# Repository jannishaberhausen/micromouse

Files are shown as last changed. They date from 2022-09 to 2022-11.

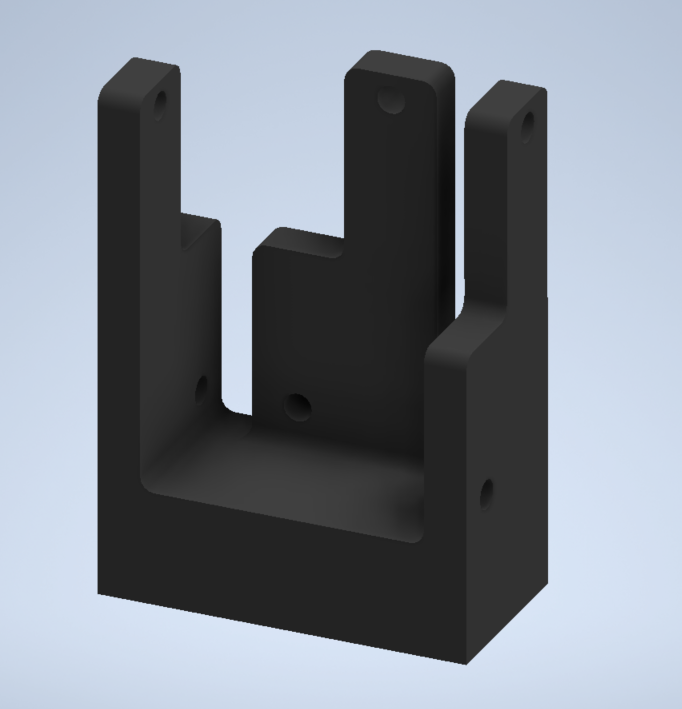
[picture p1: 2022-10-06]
CAD/3d_print/png/sg_sensor_mount.PNG

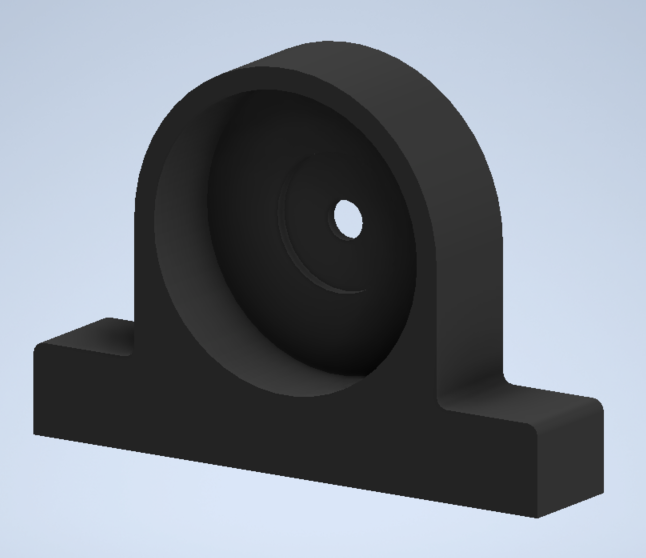
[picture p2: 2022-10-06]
CAD/3d_print/png/sg_motor_mount.PNG

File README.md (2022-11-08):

# SPEEDY GONZALES - A MICROMOUSE PROJECT
## Don't Call It Micromouse - Call It Megamouse
### Ever wondered what Speedy Gonzales does nowadys?

---

**From Wikipedia:**
Micromouse is an event where small robot mice solve a 16×16 maze. It began in the late 1970s. Events are held worldwide, and are most popular in the UK, U.S., Japan, Singapore, India, South Korea and becoming popular in subcontinent countries such as Sri Lanka.

The maze is made up of a 16×16 grid of cells, each 180 mm square with walls 50 mm high. The mice are completely autonomous robots that must find their way from a predetermined starting position to the central area of the maze unaided. The mouse needs to keep track of where it is, discover walls as it explores, map out the maze and detect when it has reached the goal. Having reached the goal, the mouse will typically perform additional searches of the maze until it has found an optimal route from the start to the finish. Once the optimal route has been found, the mouse will run that route in the shortest possible time.

Competitions and conferences are still run regularly.

----

Watch a video of Speedy Gonzales in action [here](https://youtu.be/TwjPslRqBsg).

### Getting Started

Notice `main.c` starts the T1 timer `startTimer()` and the finite state machine (FSM) `plannerFSM()` which realizes the planning of mouse motions before running in an infinite loop in which the behaviour is controlled by the planning FSM and the motion FSM which in turn is called every 50 ms by a timer interupt in T1 (see `timer.c`).
    
The most important motions (and their respective controllers) are defined in `mouse_motion.c` and the business logic for the path planning is implemented in `pathfinder.c`.

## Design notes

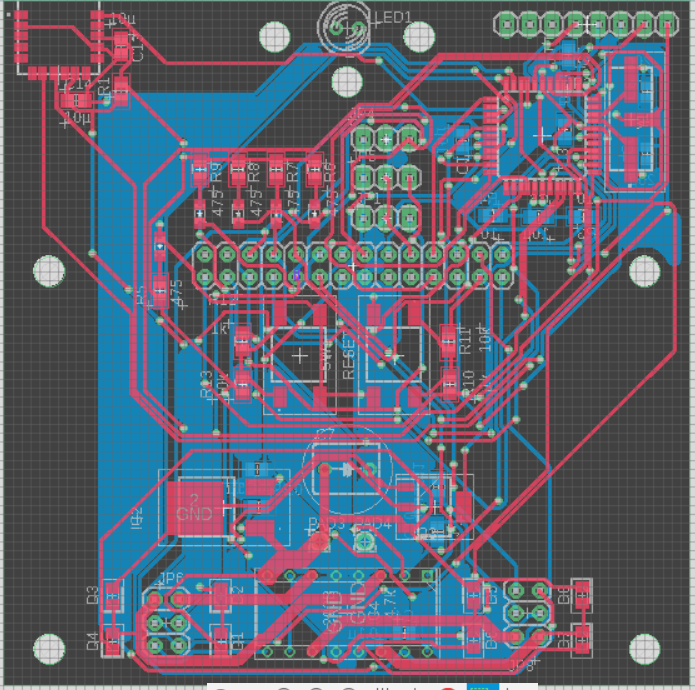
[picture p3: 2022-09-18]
CAD/PCB/speedy_gonzales_board.PNG

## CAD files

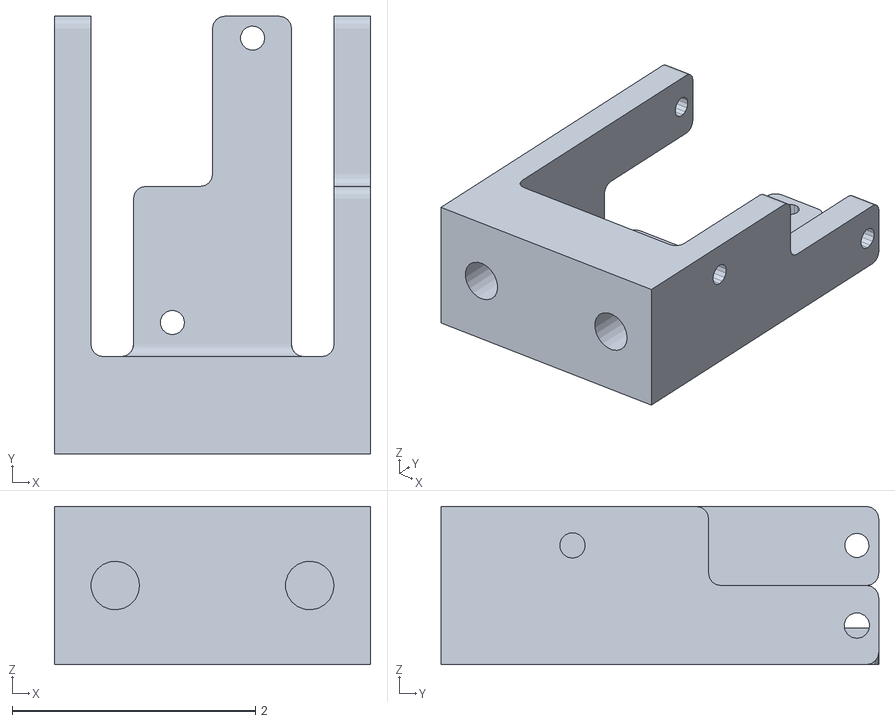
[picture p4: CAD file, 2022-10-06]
CAD/3d_print/stl/sg_sensor_mount.stl
2.60 x 3.60 x 1.30

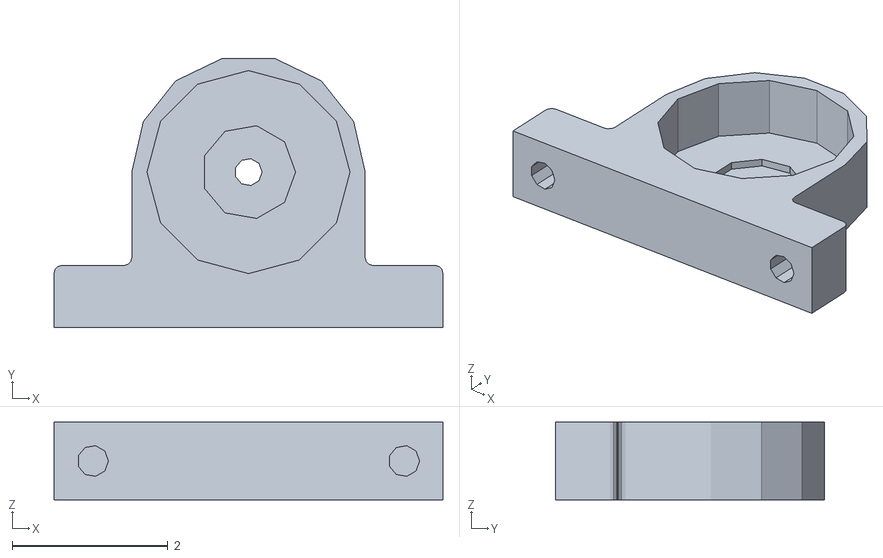
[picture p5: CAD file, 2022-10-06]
CAD/3d_print/stl/sg_motor_mount.stl
5.00 x 3.46 x 1.00

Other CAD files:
CAD/3d_print/dwg/sg_motor_mount.dwg
CAD/3d_print/dwg/sg_sensor_mount.dwg
CAD/3d_print/parts/sg_motor_mount.ipt
CAD/3d_print/parts/sg_sensor_mount.ipt

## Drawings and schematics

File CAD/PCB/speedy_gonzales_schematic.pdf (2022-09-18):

# AN5 AN⁵

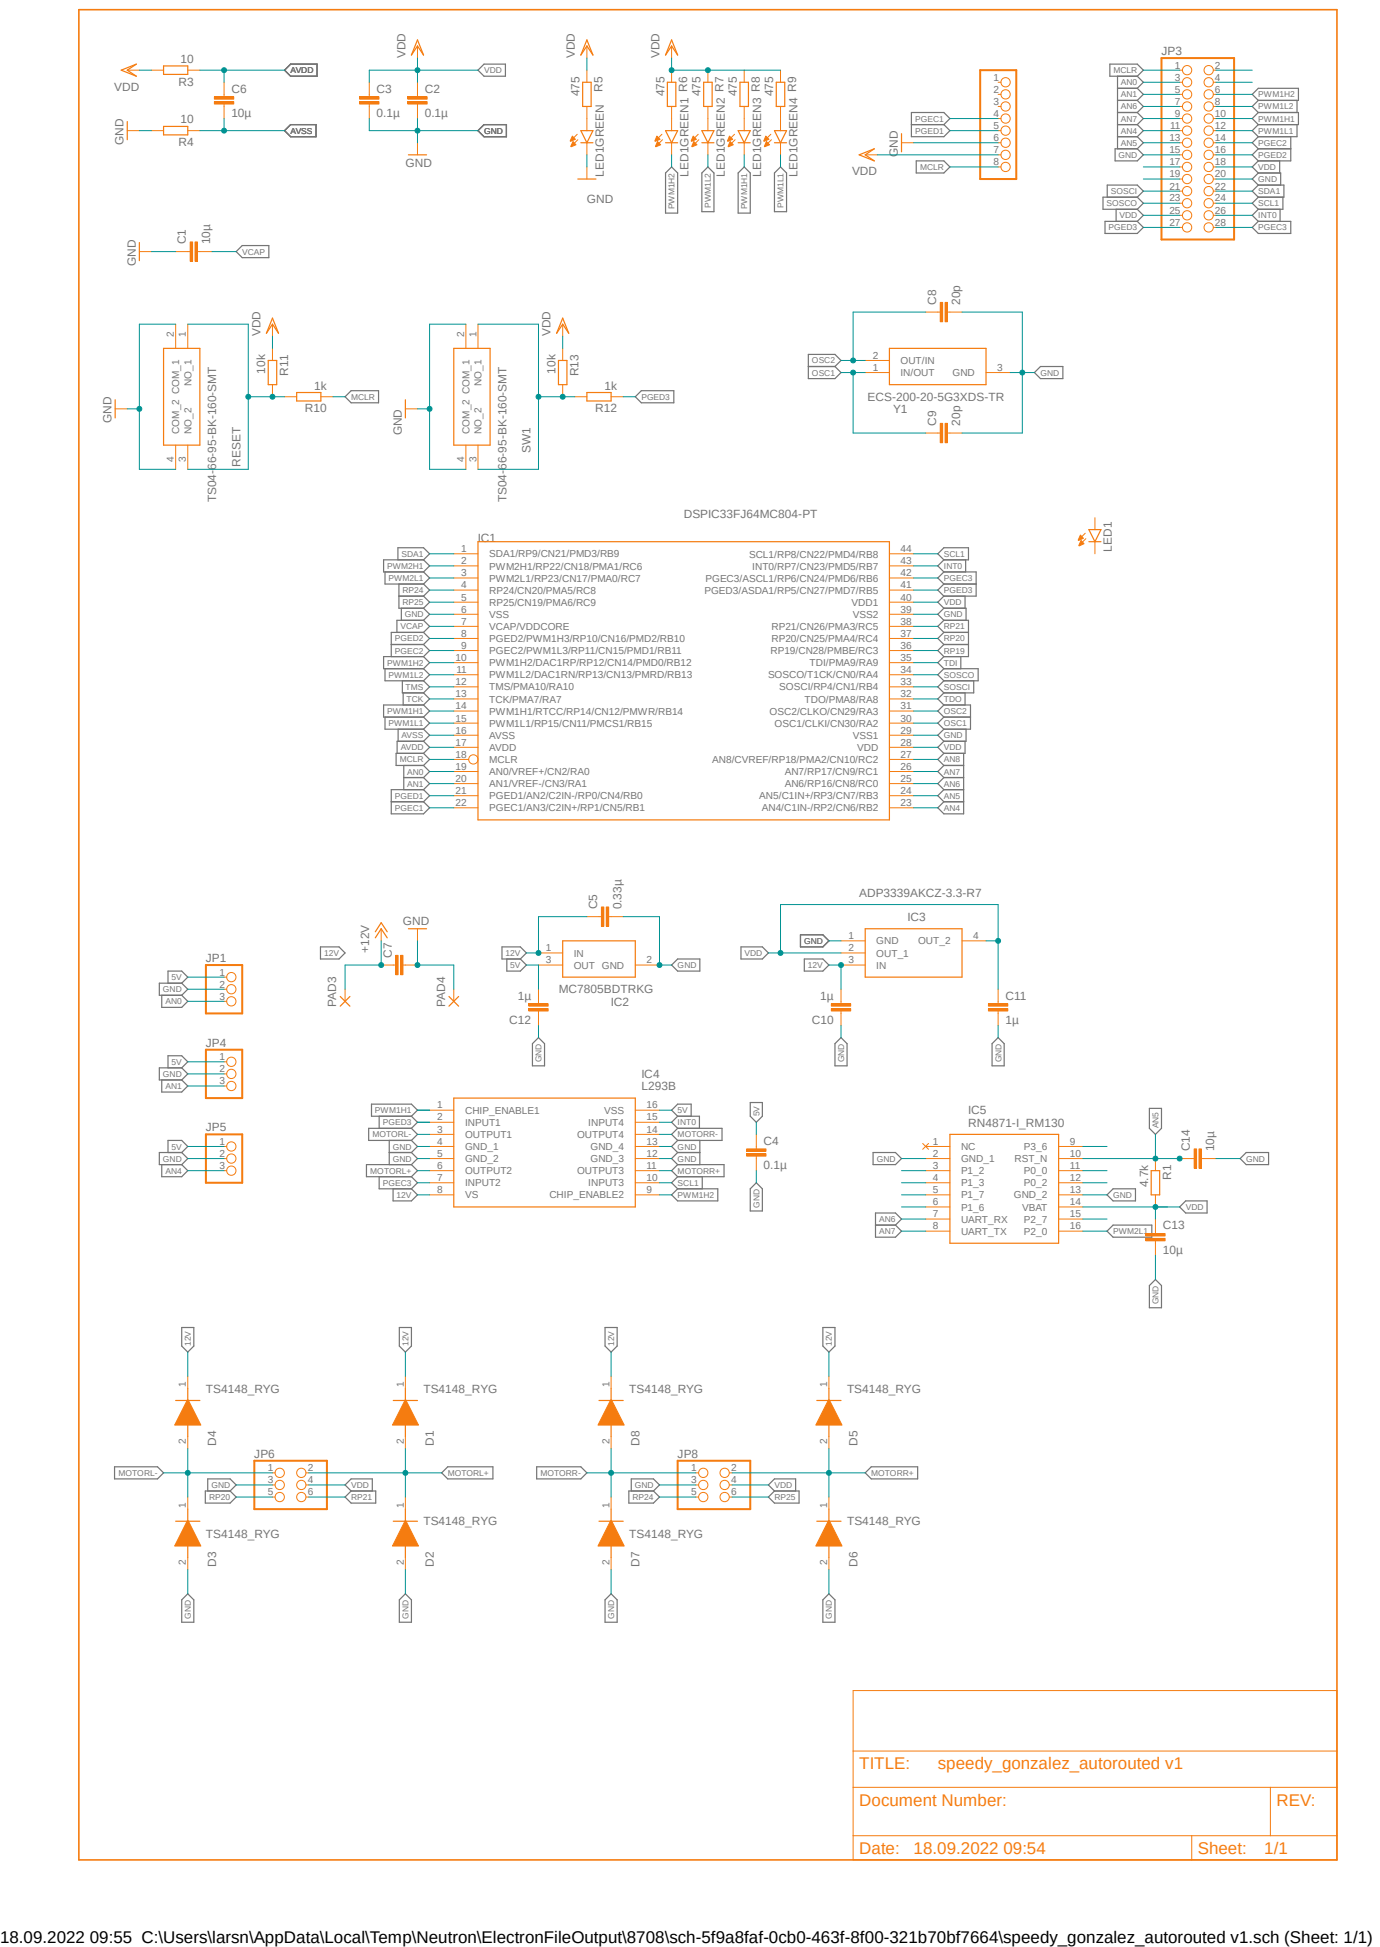
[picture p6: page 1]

GND GND

Document Number: | REV:

Date: 18.09.2022 09:54 | Sheet: 1/1

18.09.2022 09:55 C:\Users\larsn\AppData\Local\Temp\Neutron\ElectronFileOutput\8708\sch-5f9a8faf-0cb0-463f-8f00-321b70bf7664\speedy_gonzalez_autorouted v1.sch (Sheet: 1/1)

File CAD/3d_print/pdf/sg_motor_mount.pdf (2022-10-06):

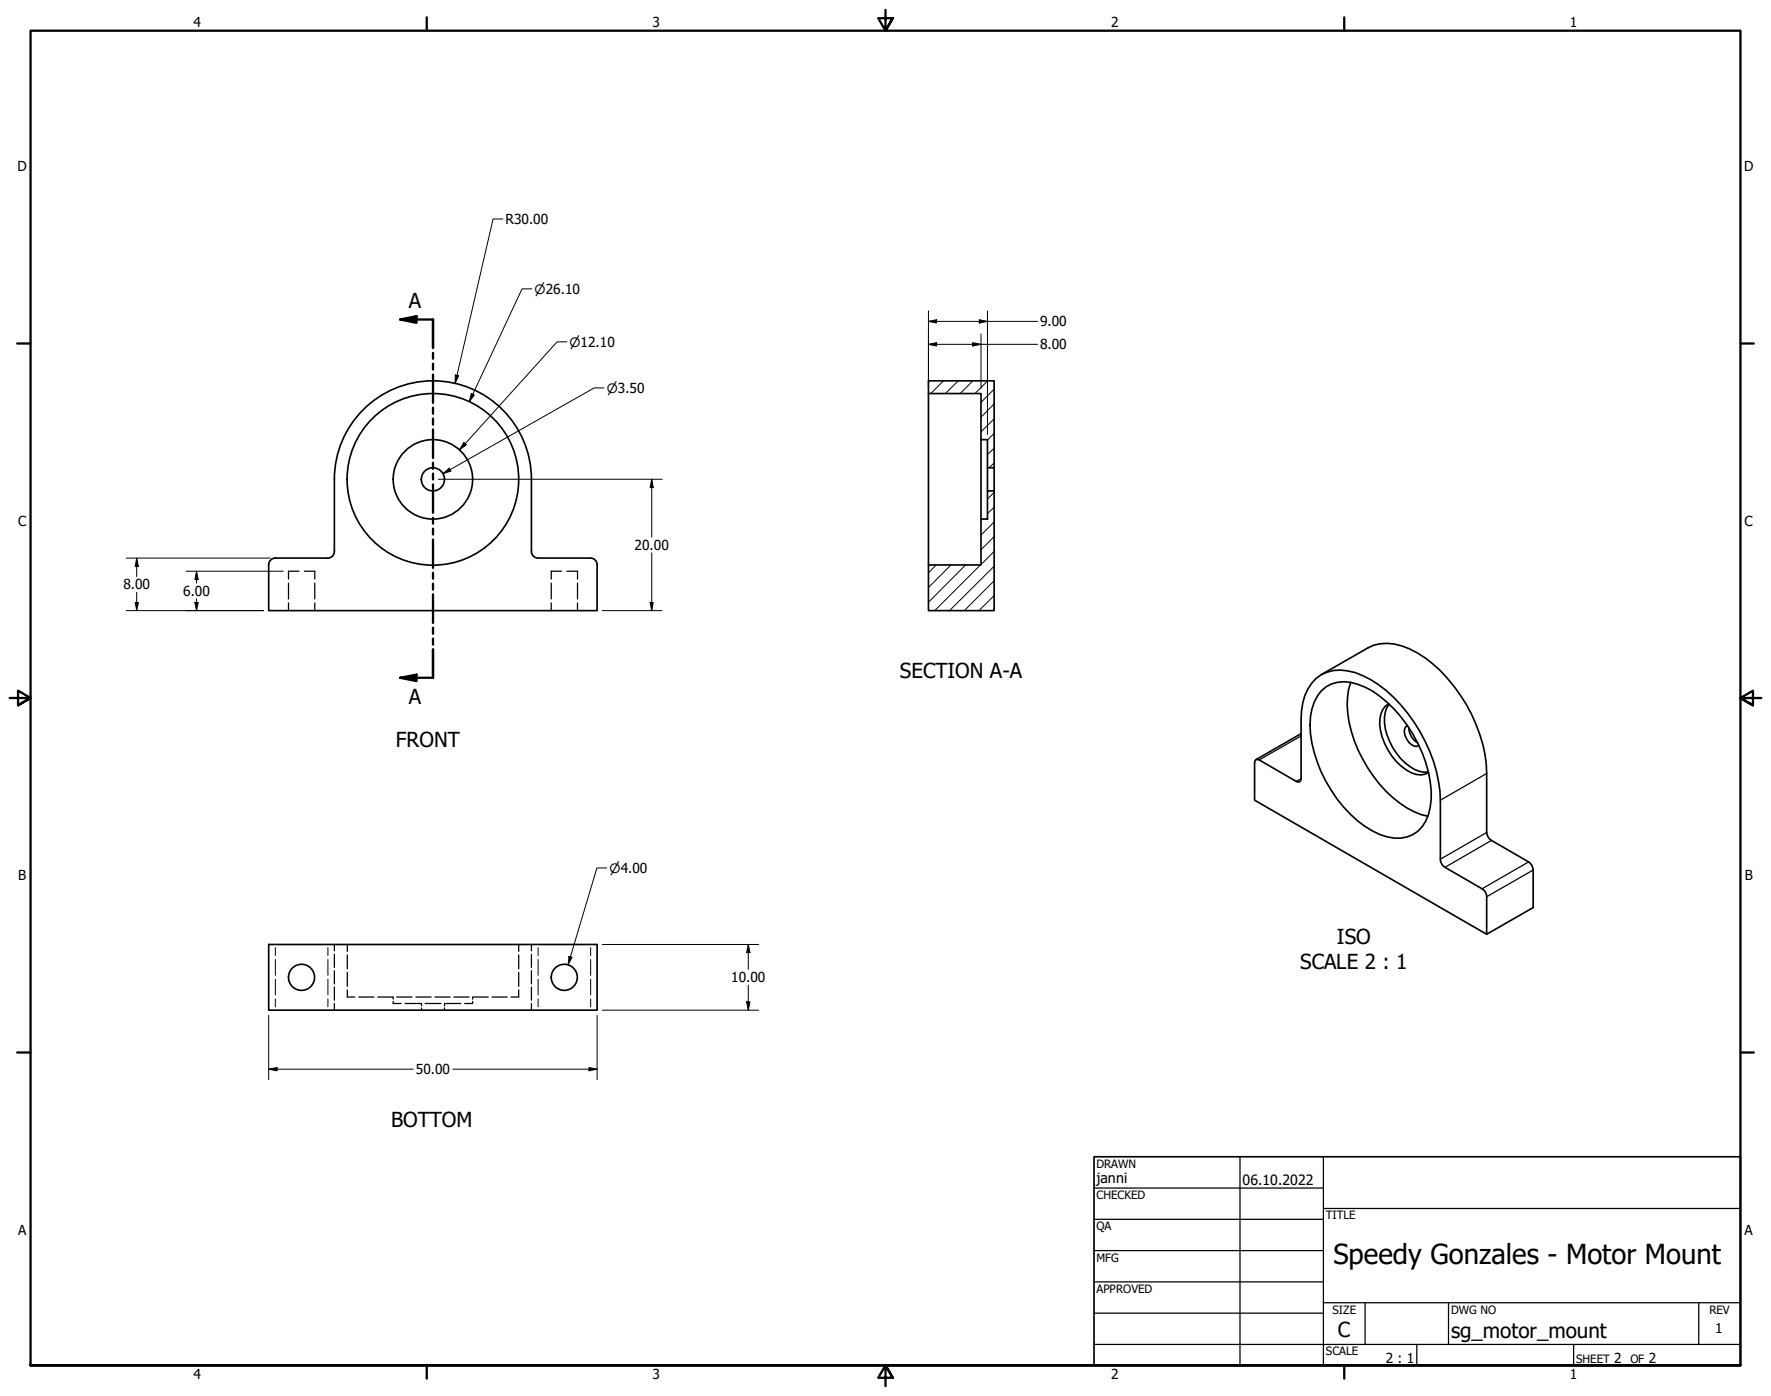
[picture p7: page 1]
SCALE 2 : 1; SECTION A-A

DRAWN janni | 06.10.2022

CHECKED

TITLE
Speedy Gonzales - Motor Mount

MFG

APPROVED

SIZE C | DWG NO sg_motor_mount | REV 1

SCALE 2 : 1 | | SHEET 2 OF 2

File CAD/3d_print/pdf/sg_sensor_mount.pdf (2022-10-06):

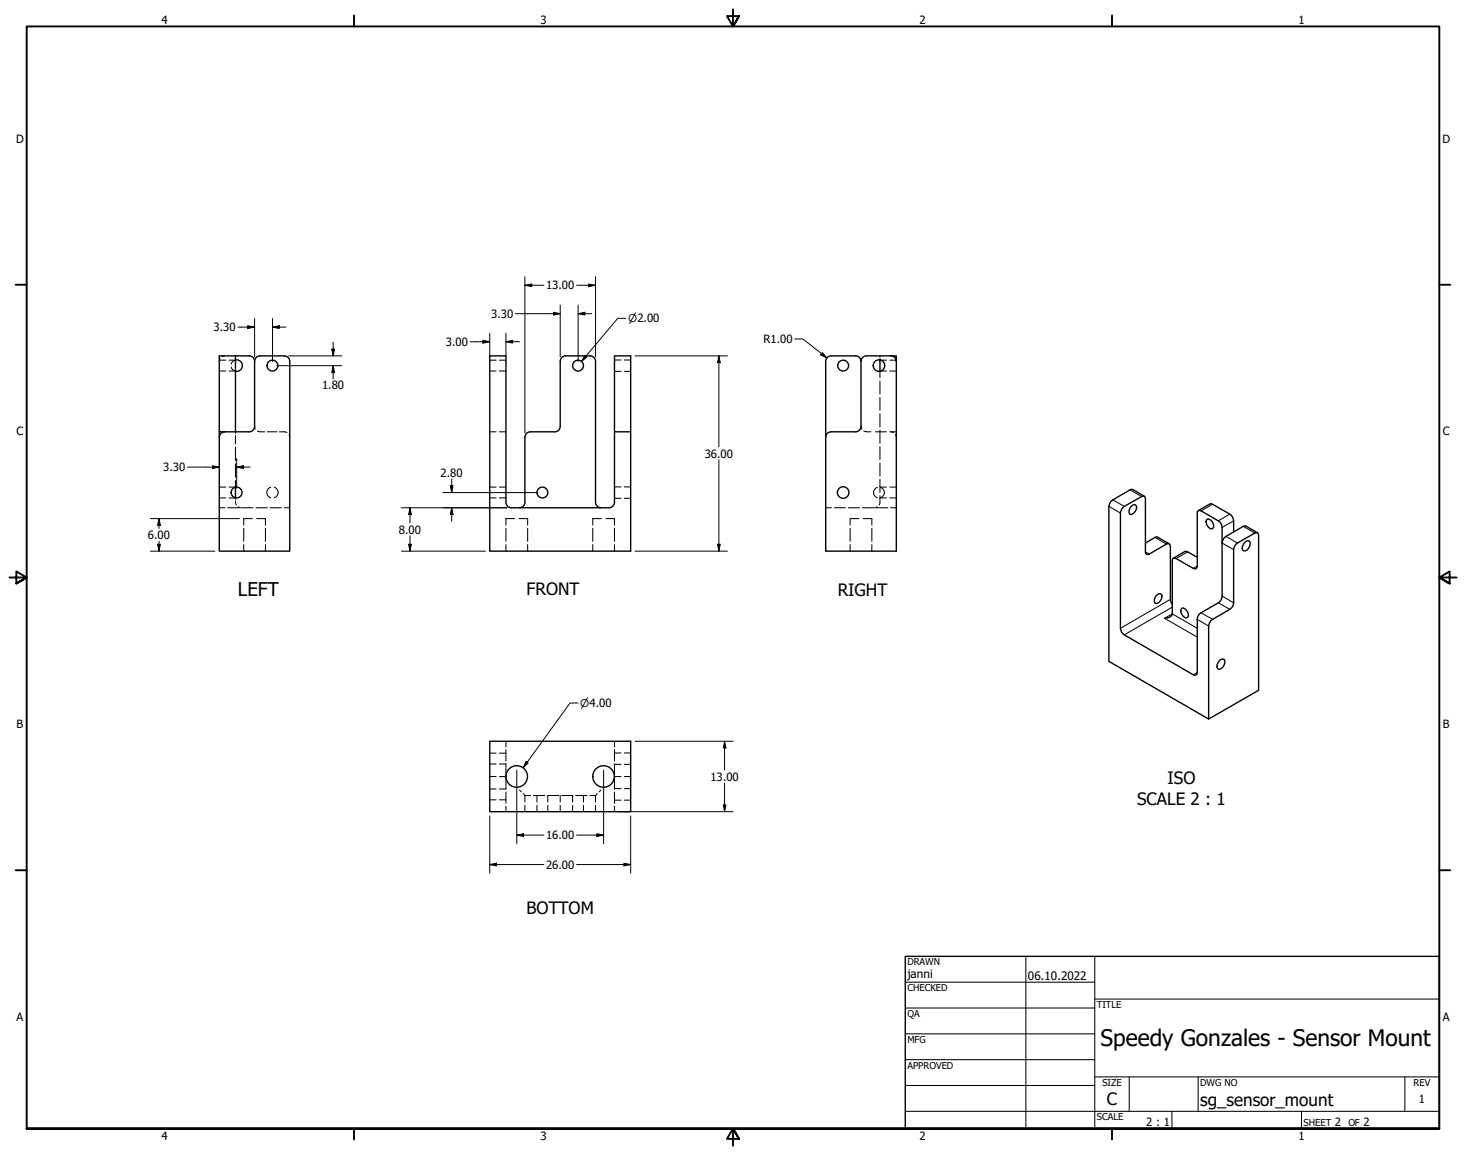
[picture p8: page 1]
SCALE 2 : 1

DRAWN janni | 06.10.2022

CHECKED

TITLE
Speedy Gonzales - Sensor Mount

MFG

APPROVED

SIZE C | DWG NO sg_sensor_mount | REV 1

SCALE 2 : 1 | | SHEET 2 OF 2

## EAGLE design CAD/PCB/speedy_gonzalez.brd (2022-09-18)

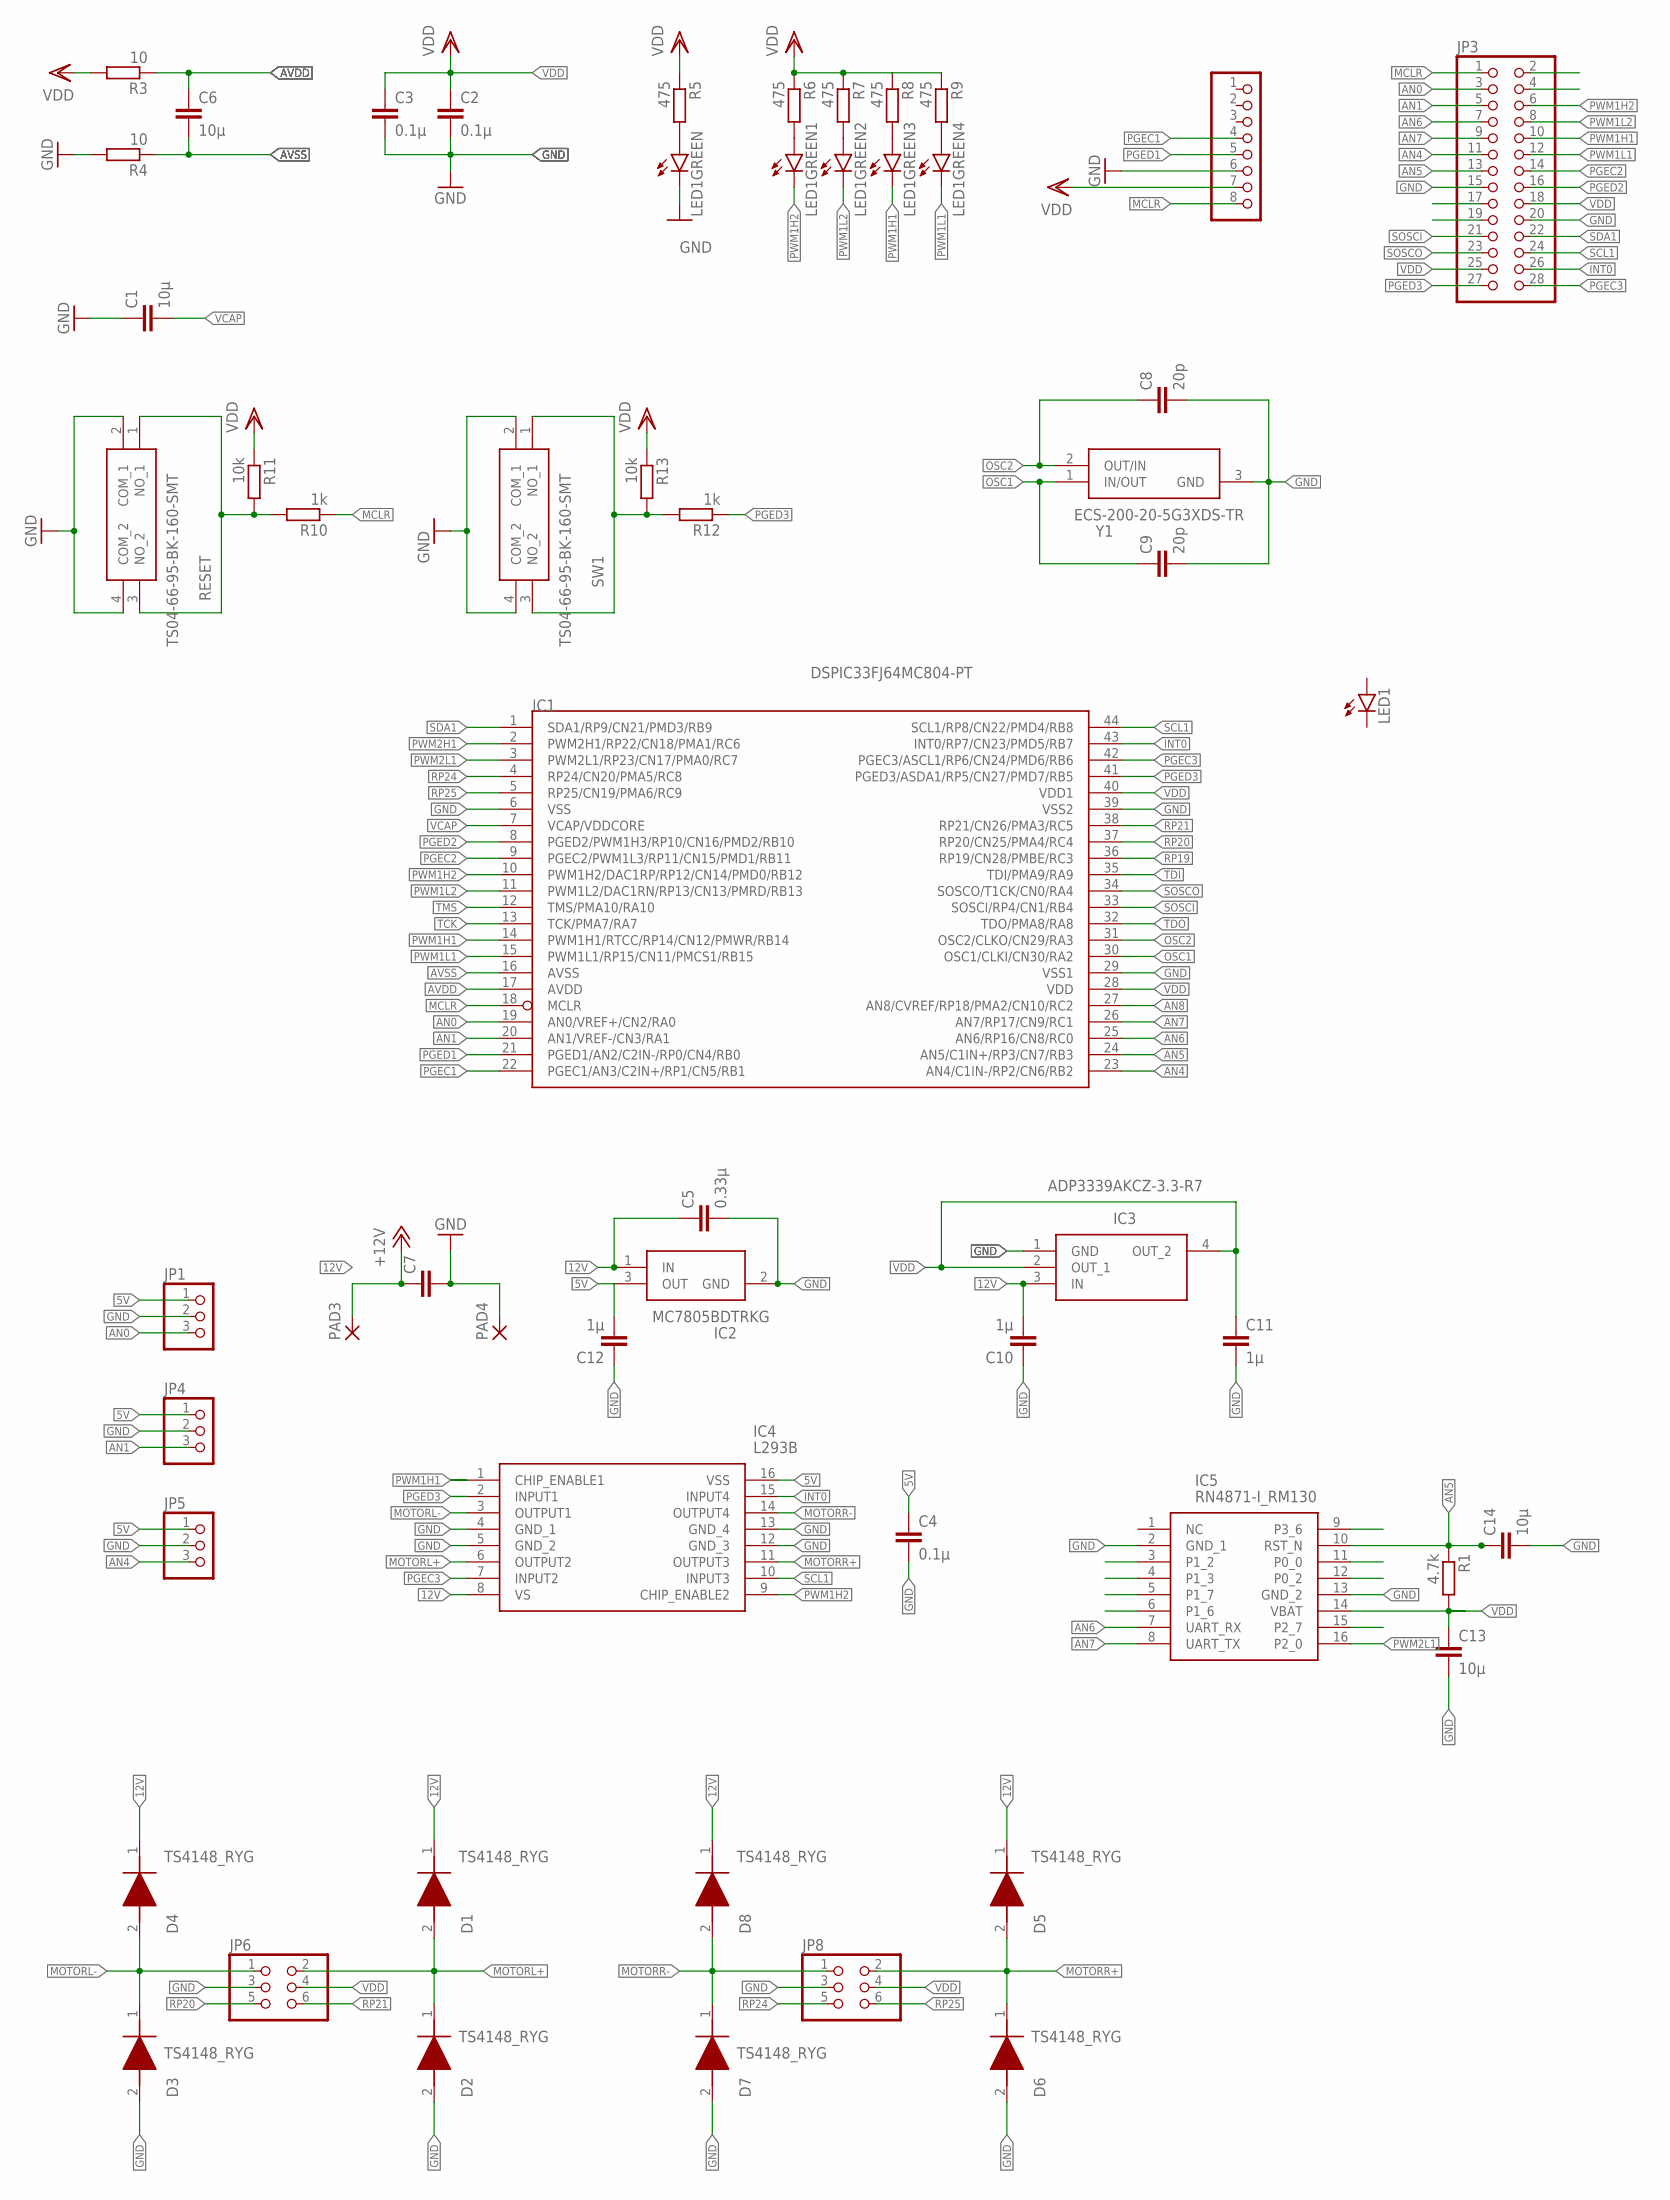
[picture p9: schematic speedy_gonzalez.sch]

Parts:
C1, C6, C13, C14: 10µ; C0805
C2, C3, C4: 0.1µ; C0805
C5: 0.33µ; C0805
C7: C-EU050-055X075; C050-055X075
C8, C9: 20p; C0805
C10, C11, C12: 1µ; C0805
D1, D2, D3, D4, D5, D6, D7, D8: TS4148_RYG; DIOC2012X85N
IC1: DSPIC33FJ64MC804-PT; TQFP44
IC2: MC7805BDTRKG; LM317MADTRKG
IC3: ADP3339AKCZ-3.3-R7; SOT230P700X180-4N
IC4: L293B; DIP850W50P254L2000H510Q16N
IC5: RN4871-I_RM130; RN4871
JP1, JP4, JP5: PINHD-1X3; 1X03
JP2: PINHD-1X8; 1X08
JP3: PINHD-2X14; 2X14
JP6, JP8: PINHD-2X3; 2X03
LED1: LED5MM
LED1GREEN, LED1GREEN1, LED1GREEN2, LED1GREEN3, LED1GREEN4: LEDCHIPLED_0805; CHIPLED_0805
PAD3, PAD4: 2,15/1,0
R1: 4.7k; R0805
R3, R4: 10; R0805
R5, R6, R7, R8, R9: 475; R0805
R10, R12: 1k; R0805
R11, R13: 10k; R0805
RESET: TS04-66-95-BK-160-SMT; TS046695BK160SMT
SW1: TS04-66-95-BK-160-SMT; TS046695BK160SMT
Y1: ECS-200-20-5G3XDS-TR; ECS250205G3XDSFTR

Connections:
5V: C4.1, C12.2, IC2.3 (OUT), IC4.16 (VSS), JP1.1, JP4.1, JP5.1
12V: C5.1, C7.1, C10.2, D1.1 (K), D4.1 (K), D5.1 (K), D8.1 (K), IC2.1 (IN), IC3.3 (IN), IC4.8 (VS), PAD3.1
AN0: IC1.19 (AN0/VREF+/CN2/RA0), JP1.3, JP3.3
AN1: IC1.20 (AN1/VREF-/CN3/RA1), JP3.5, JP4.3
AN4: IC1.23 (AN4/C1IN-/RP2/CN6/RB2), JP3.11, JP5.3
AN5: C14.1, IC1.24 (AN5/C1IN+/RP3/CN7/RB3), IC5.10 (RST_N), JP3.13, R1.1
AN6: IC1.25 (AN6/RP16/CN8/RC0), IC5.7 (UART_RX), JP3.7
AN7: IC1.26 (AN7/RP17/CN9/RC1), IC5.8 (UART_TX), JP3.9
AN8: IC1.27 (AN8/CVREF/RP18/PMA2/CN10/RC2)
AVDD: C6.1, IC1.17 (AVDD), R3.1
AVSS: C6.2, IC1.16 (AVSS), R4.1
GND: C1.1, C2.2, C3.2, C4.2, C5.2, C7.2, C8.2, C9.2, C10.1, C11.2, C12.1, C13.2, C14.2, D2.2 (A), D3.2 (A), D6.2 (A), D7.2 (A), IC1.6 (VSS), IC1.29 (VSS1), IC1.39 (VSS2), IC2.2 (GND), IC3.1 (GND), IC4.4 (GND_1), IC4.5 (GND_2), IC4.12 (GND_3), IC4.13 (GND_4), IC5.2 (GND_1), IC5.13 (GND_2), JP1.2, JP2.6, JP3.15, JP3.20, JP4.2, JP5.2, JP6.3, JP8.3, LED1GREEN.C, PAD4.1, R4.2, RESET.2 (COM_1), RESET.4 (COM_2), SW1.2 (COM_1), SW1.4 (COM_2), Y1.3 (GND)
INT0: IC1.43 (INT0/RP7/CN23/PMD5/RB7), IC4.15 (INPUT4), JP3.26
MCLR: IC1.18 (MCLR), JP2.8, JP3.1, R10.1
MOTORL+: D1.2 (A), D2.1 (K), IC4.6 (OUTPUT2), JP6.2
MOTORL-: D3.1 (K), D4.2 (A), IC4.3 (OUTPUT1), JP6.1
MOTORR+: D5.2 (A), D6.1 (K), IC4.11 (OUTPUT3), JP8.2
MOTORR-: D7.1 (K), D8.2 (A), IC4.14 (OUTPUT4), JP8.1
unnamed: LED1GREEN.A, R5.2
unnamed: LED1GREEN1.A, R6.2
unnamed: LED1GREEN2.A, R7.2
unnamed: LED1GREEN3.A, R8.2
unnamed: R12.2, R13.2, SW1.1 (NO_1), SW1.3 (NO_2)
unnamed: R10.2, R11.2, RESET.1 (NO_1), RESET.3 (NO_2)
unnamed: LED1GREEN4.A, R9.2
OSC1: C9.1, IC1.30 (OSC1/CLKI/CN30/RA2), Y1.1 (IN/OUT)
OSC2: C8.1, IC1.31 (OSC2/CLKO/CN29/RA3), Y1.2 (OUT/IN)
PGEC1: IC1.22 (PGEC1/AN3/C2IN+/RP1/CN5/RB1), JP2.4
PGEC2: IC1.9 (PGEC2/PWM1L3/RP11/CN15/PMD1/RB11), JP3.14
PGEC3: IC1.42 (PGEC3/ASCL1/RP6/CN24/PMD6/RB6), IC4.7 (INPUT2), JP3.28
PGED1: IC1.21 (PGED1/AN2/C2IN-/RP0/CN4/RB0), JP2.5
PGED2: IC1.8 (PGED2/PWM1H3/RP10/CN16/PMD2/RB10), JP3.16
PGED3: IC1.41 (PGED3/ASDA1/RP5/CN27/PMD7/RB5), IC4.2 (INPUT1), JP3.27, R12.1
PWM1H1: IC1.14 (PWM1H1/RTCC/RP14/CN12/PMWR/RB14), IC4.1 (CHIP_ENABLE1), JP3.10, LED1GREEN3.C
PWM1H2: IC1.10 (PWM1H2/DAC1RP/RP12/CN14/PMD0/RB12), IC4.9 (CHIP_ENABLE2), JP3.6, LED1GREEN1.C
PWM1L1: IC1.15 (PWM1L1/RP15/CN11/PMCS1/RB15), JP3.12, LED1GREEN4.C
PWM1L2: IC1.11 (PWM1L2/DAC1RN/RP13/CN13/PMRD/RB13), JP3.8, LED1GREEN2.C
PWM2H1: IC1.2 (PWM2H1/RP22/CN18/PMA1/RC6)
PWM2L1: IC1.3 (PWM2L1/RP23/CN17/PMA0/RC7), IC5.16 (P2_0)
RP19: IC1.36 (RP19/CN28/PMBE/RC3)
RP20: IC1.37 (RP20/CN25/PMA4/RC4), JP6.5
RP21: IC1.38 (RP21/CN26/PMA3/RC5), JP6.6
RP24: IC1.4 (RP24/CN20/PMA5/RC8), JP8.5
RP25: IC1.5 (RP25/CN19/PMA6/RC9), JP8.6
SCL1: IC1.44 (SCL1/RP8/CN22/PMD4/RB8), IC4.10 (INPUT3), JP3.24
SDA1: IC1.1 (SDA1/RP9/CN21/PMD3/RB9), JP3.22
SOSCI: IC1.33 (SOSCI/RP4/CN1/RB4), JP3.21
SOSCO: IC1.34 (SOSCO/T1CK/CN0/RA4), JP3.23
TCK: IC1.13 (TCK/PMA7/RA7)
TDI: IC1.35 (TDI/PMA9/RA9)
TDO: IC1.32 (TDO/PMA8/RA8)
TMS: IC1.12 (TMS/PMA10/RA10)
VCAP: C1.2, IC1.7 (VCAP/VDDCORE)
VDD: C2.1, C3.1, C11.1, C13.1, IC1.28 (VDD), IC1.40 (VDD1), IC3.2 (OUT_1), IC3.4 (OUT_2), IC5.14 (VBAT), JP2.7, JP3.18, JP3.25, JP6.4, JP8.4, R1.2, R3.2, R5.1, R6.1, R7.1, R8.1, R9.1, R11.1, R13.1

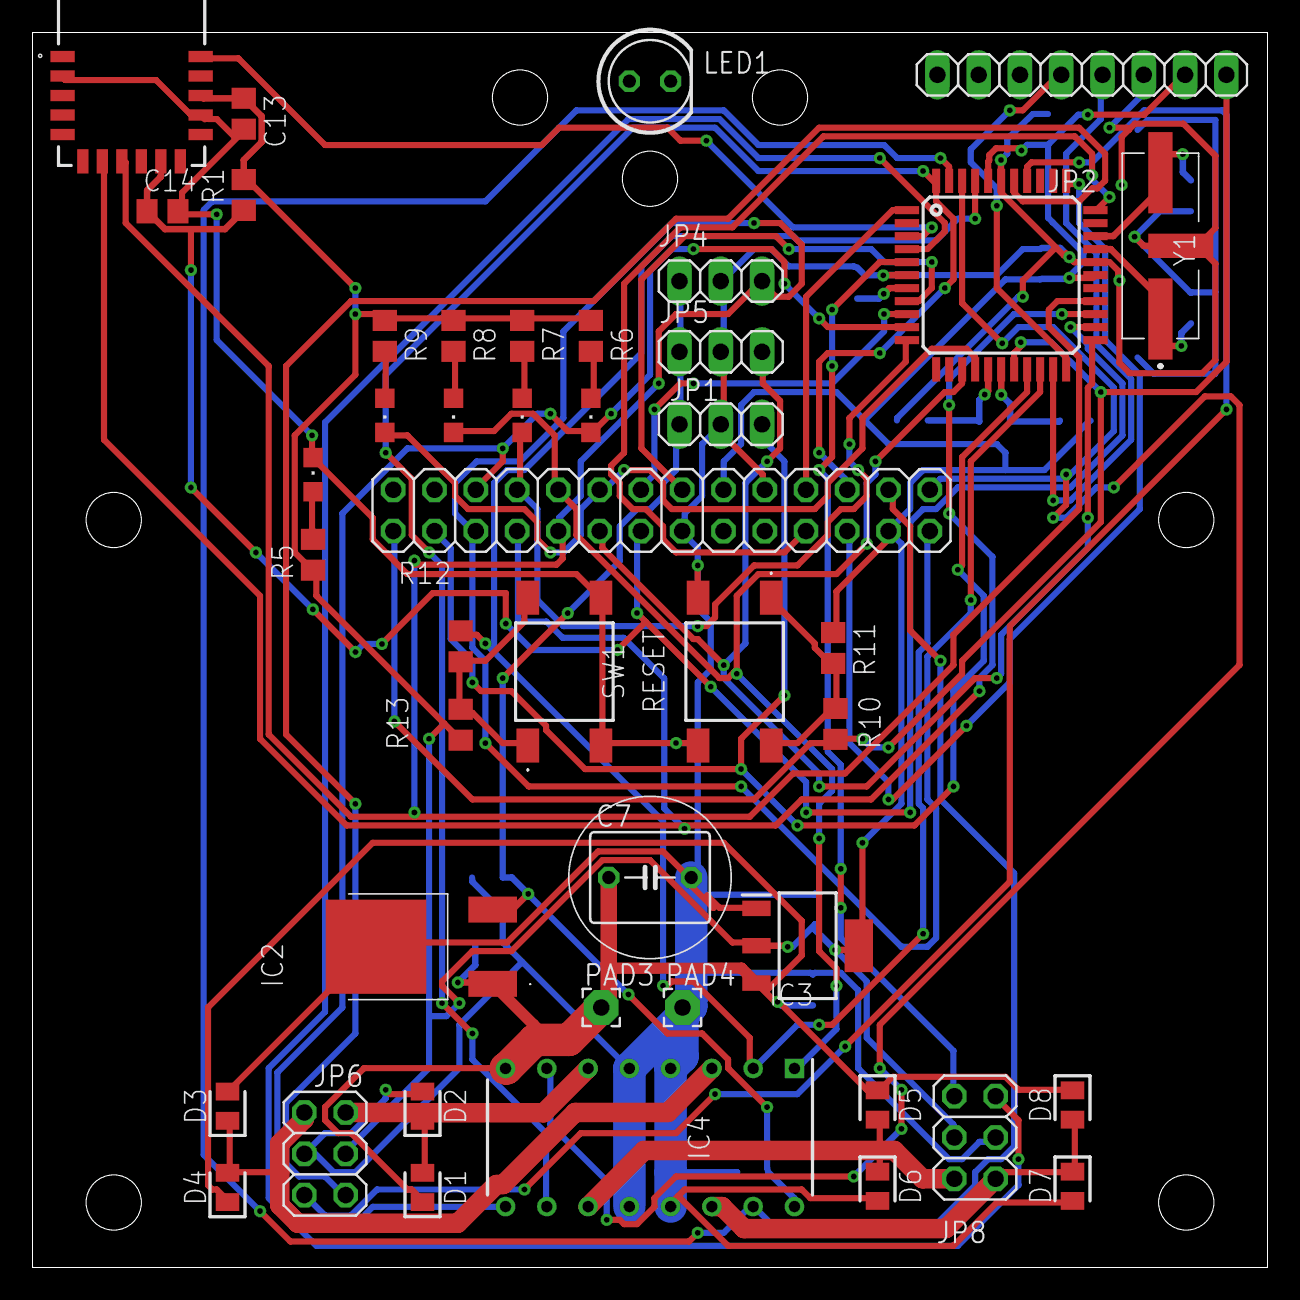
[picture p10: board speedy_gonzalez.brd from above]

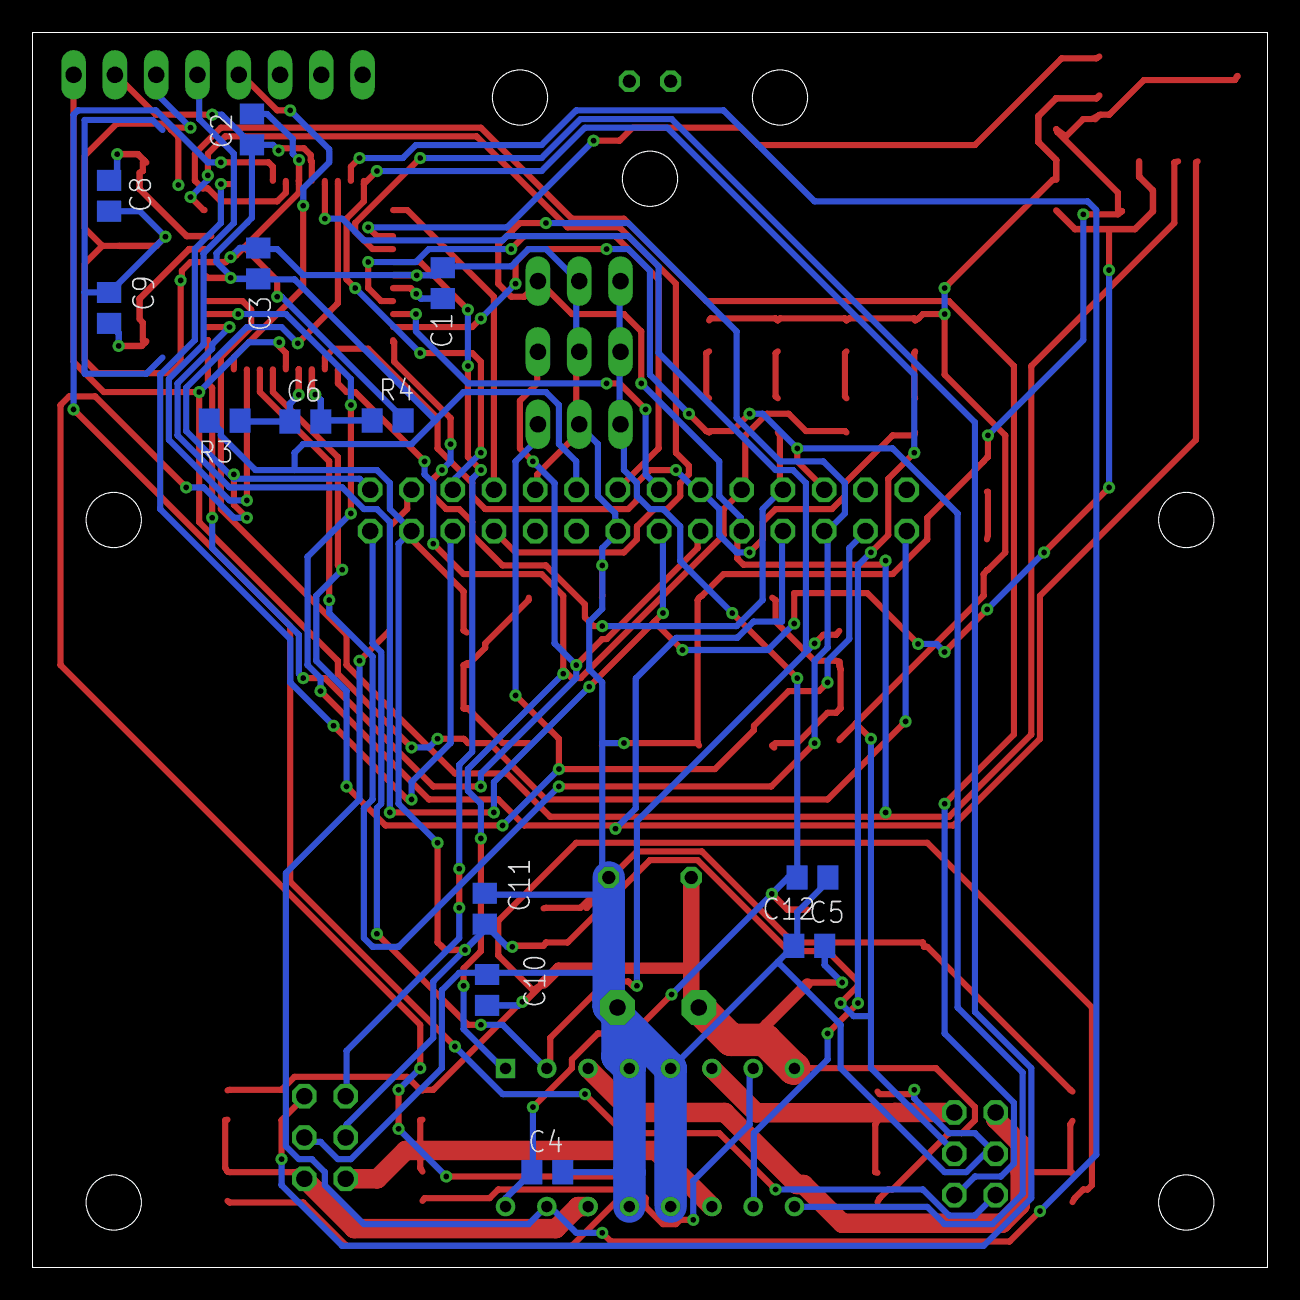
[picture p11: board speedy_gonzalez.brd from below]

Board: 2 copper layers, 76.0 x 76.0 mm, 57 parts (13 on the bottom side), 47 nets.

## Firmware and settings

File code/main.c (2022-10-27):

/// Configuration Bits---------------------------

// FBS
#pragma config BWRP = WRPROTECT_OFF     // Boot Segment Write Protect (Boot Segment may be written)
#pragma config BSS = NO_FLASH           // Boot Segment Program Flash Code Protection (No Boot program Flash segment)

// FGS
#pragma config GWRP = OFF               // General Code Segment Write Protect (User program memory is not write-protected)
#pragma config GSS = OFF                // General Segment Code Protection (User program memory is not code-protected)

// FOSCSEL
#pragma config FNOSC = FRC              // Start with Internal RC Oscillator
#pragma config IESO = OFF               // Internal External Switch Over Mode (Start-up device with FRC, then automatically switch to user-selected oscillator source when ready)

// FOSC
#pragma config POSCMD = HS              // Primary Oscillator Source (HS Oscillator Mode)
#pragma config OSCIOFNC = OFF           // OSC2 Pin Function (OSC2 pin has clock out function)
#pragma config IOL1WAY = OFF            // Peripheral Pin Select Configuration (Allow Multiple Re-configurations)
#pragma config FCKSM = CSECMD           // Clock Switching and Monitor (Both Clock Switching and Fail-Safe Clock Monitor are enabled)

// FWDT
#pragma config WDTPOST = PS1            // Watchdog Timer Postscaler (1:1)
#pragma config WDTPRE = PR128           // WDT Prescaler (1:128)
#pragma config WINDIS = OFF             // Watchdog Timer Window (Watchdog Timer in Non-Window mode)
#pragma config FWDTEN = OFF             // Watchdog Timer Enable (Watchdog timer enabled/disabled by user software)

// FPOR
#pragma config FPWRT = PWR128           // POR Timer Value (128ms)
#pragma config ALTI2C = ON              // Alternate I2C  pins (I2C mapped to SDA1/SCL1 pins)
#pragma config LPOL = ON                // Motor Control PWM Low Side Polarity bit (PWM module low side output pins have active-high output polarity)
#pragma config HPOL = ON                // Motor Control PWM High Side Polarity bit (PWM module high side output pins have active-high output polarity)
#pragma config PWMPIN = ON              // Motor Control PWM Module Pin Mode bit (PWM module pins controlled by PORT register at device Reset)

// FICD
#pragma config ICS = PGD1               // Comm Channel Select (Communicate on PGC1/EMUC1 and PGD1/EMUD1)
#pragma config JTAGEN = OFF             // JTAG Port Enable (JTAG is Disabled)


/// Include headers-------------------------------
#include "xc.h"
#include "IOconfig.h"
#include "button.h"
#include "timer.h"
#include "pwm.h"
#include "adc.h"
#include "dma.h"
#include "pathfinder.h"
#include "pathfinder_tests.h"
#include "mouse_motion.h"


int main() 
{
    
     /*
      * oscillator setup --------------------------------------------------
      * The external oscillator runs at 20MHz
      * PLL is used to generate 80MHz clock (FOSC)
      * The relationship between oscillator and cycle frequency: FCY = FOSC/2
      * Have a look at "PLL Configuration" paragraph in the mcu manual
      * 
      * N1 = 3  to reach VCO input between 0.8 .. 8MHz          (20MHz / 3 = 6.667MHz)
      * M  = 24 to reach VCO output between 100 .. 200MHz       (6.667MHz * 24 = 160MHz)
      * N2 = 2  to reach output frequency between 12.5 .. 80MHz (160MHz / 2 = 80MHz)
      * 
      * Result: FCY = 0.5 * (20MHz*24/(3*2)) = 40 MIPS, Tcycle=25nsec
      * ------------------------------------------------------------------*/
    PLLFBDbits.PLLDIV = 22;           //set PPL to M=24 (22+2)
    CLKDIVbits.PLLPRE = 1;            //N1 = input/3
    CLKDIVbits.PLLPOST = 0;           //N2 = output/2    
    
        /* Clock switch to incorporate PLL*/
    __builtin_write_OSCCONH( 0x03 );            // Initiate Clock Switch to Primary

    // Oscillator with PLL (NOSC=0b011)
    __builtin_write_OSCCONL( OSCCON || 0x01 );  // Start clock switching
    
    while( OSCCONbits.COSC != 0b011 );
    
    // In reality, give some time to the PLL to lock
    while (OSCCONbits.LOCK != 1); //Wait for PLL to lock
 
    setupIO(); //configures inputs and outputs
    
    //set up the 10ms timer used as base for all tests.
    /*
     * Test cases are implemented in the timer ISR. More details in timer.c
     */
    initTimer(10000);
    
    setupLED24();
    
    setupMotors();
    setupSensors();
    setupEncoders();
    resetController();
    
    // start the timer.
    /*
     * Uncomment the test case you want to run in the timer ISR in timer.c.
     */
    startTimer();
    
    // PLANNER STATE MACHINE
    plannerFSM();
    //testMotionSequence();
    //testMouseRaceSequence();
    
    
    while(1)
    {
        
       
    }
    
    return 0;
}

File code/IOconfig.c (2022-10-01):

#include "xc.h"
#include "IOconfig.h"

#include "pwm.h"
#include "button.h"
#include "motorEncoders.h"
#include "dma.h"
#include "adc.h"
#include "sharp.h"



void setupIO()
{

    int i;
    
    
    //all pins are now digital, by default they are analogue
    AD1PCFGL=0xFFFF;
    
    //sharp sensors at AN0, AN1, and AN4 are analogue
    AD1PCFGLbits.PCFG0 = 0;
    AD1PCFGLbits.PCFG1 = 0;
    AD1PCFGLbits.PCFG4 = 0;
    
    // if cutting AN1 dosn't work, make AN7 analogue
    //AD1PCFGLbits.PCFG7 = 0;
    
    // set LEDs as output
    //TRISBbits.TRISB12 = 0;
    TRISBbits.TRISB13 = 0;
    //TRISBbits.TRISB14 = 0;
    TRISBbits.TRISB15 = 0;
    
    // set MOTINxx as outputs
    TRISBbits.TRISB5 = 0;
    TRISBbits.TRISB6 = 0;
    TRISBbits.TRISB8 = 0;
    TRISBbits.TRISB7 = 0;
    
    // UART1 TX as output
    // if cutting AN1 doesn't work, delete this
    TRISCbits.TRISC1 = 0;
    

    ///////////////////////// PIN MAPPING ///////////////////////////
    
    //before we map, we need to unlock
    // clear bit 6 (unlock, they are usually write protected)
    __builtin_write_OSCCONL(OSCCON & 0xbf);
    
    
    // PERIPHERAL receives data from which INPUT PIN
    
    // UART1 RX on RP16
    RPINR18bits.U1RXR = 16;

    // QE1 on RP20 and RP21
    RPINR14bits.QEA1R = 20;
    RPINR14bits.QEB1R = 21;
    
    // QE2 on RP24 and RP25
    RPINR16bits.QEA2R = 24;
    RPINR16bits.QEB2R = 25;
    
    
    
    
    //OUTPUT PIN receives data from which PERIPHERAL, 
    //see table 11-2 in datasheet to check peripheral codes 
    
    // UART1 TX goes to RP17
    // if cutting AN1 doesn't work, delete this
    RPOR8bits.RP17R = 0b00011;

    
    
    
   
    //after mapping we lock again
    // Lock PPS registers (lock again!)
     __builtin_write_OSCCONL(OSCCON | 0x40);
     
    // short dirty delay for changes to take effect
    for (i = 0; i < 30000; i++);

    
}

/////////////////////////////////////////////////////////////////////////////
//    Wrapper functions initializing the necessary hardware modules for    //
//                         high-level functions                            //
/////////////////////////////////////////////////////////////////////////////

/*
 * These functions call the low-level initialization functions whenever the
 * corresponding module is required for the higher-level function.
 * Therefore, some setup functions will be called more often than necessary.
 * This is prefered over calling them manually due to simplicity, and ensures
 * that the modules are always in a known sate.
 * Other setup functions may modify that state (e.g. for PWM that's done all 
 * the time), but not completely reinitialize them if they are not directly
 * needed.
 */



/**
 * Uses LED2 and LED4 as output.
 * 
 * For binary output without PWM, makes it possible to use these LEDs 
 * at the same time as the motors or the switch.
 * 
 * Changes only the LED2/4 pins, 
 * motors, encoders, switch, and sensors are unaffected.
 * 
 * Calls no other setup functions.
 */
void setupLED24() {
    // disable PWM if necessary
    if(PWM1CON1bits.PEN1L == 1) {
        // LED2 is set to PWM. Disable it
        PWM1CON1bits.PEN1L = 0;
    }
    if(PWM1CON1bits.PEN2L == 1) {
        // LED4 is set to PWM. Disable it
        PWM1CON1bits.PEN2L = 0;
    }
    LED2 = LEDOFF;
    LED4 = LEDOFF;
}


/**
 * Uses LED2 and LED4 as PWM output.
 * 
 * Can not me used while the motors are active, but can be used 
 * together with the switch.
 * 
 * Changes the LED2/4 output pins and disables. 
 * Encoders, switch and sensors are unaffected.
 * 
 * Calls setupPWM().
 */
void setupLED24_PWM() {
    // reset PWM module
    initPWM();
    
    // disable motors
    //MOTENL = 0;
    //MOTENR = 0;
    
    // enable PWM on LEDs
    PWM1CON1bits.PEN1L = 1;
    PWM1CON1bits.PEN2L = 1;
}


/**
 * Enables the motors.
 * 
 * Cannot be used together with LED2/4 in PWM mode or together with the switch.
 * 
 * Activates the motors, disables PWM on the LEDs and disables the switch.
 * Encoders and sensors are unaffected.
 * 
 * Calls setupPWM().
 */
void setupMotors() {
    //setupLED24();
    // disable interrupts on the switch
    CNEN2bits.CN27IE = 0;
    // TODO disable internal pullup
    // CNPU2bits.CN27PUE = 0;
    
    // Do we have to change TRISBbits.TRISB5 to output ?
    TRISBbits.TRISB5 = 0;
    
    // reset PWM module
    initPWM();
    
    // set motor directions to save, known state
    MOTINL1 = 0;
    MOTINL2 = 0;
    MOTINR1 = 0;
    MOTINR2 = 0;
        
    // enable PWM on the motors
    PWM1CON1bits.PEN1H = 1;
    PWM1CON1bits.PEN2H = 1;
}
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

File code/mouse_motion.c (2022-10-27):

/*
 * File:   mouse_motion.c
 * Author: janni
 *
 * Created on 18. September 2022, 18:57
 */


#include "xc.h"

#include "IOconfig.h"

#include "pwm.h"
#include "motorEncoders.h"
#include "dma.h"
#include "adc.h"
#include "sharp.h"
#include "mouse_motion.h"

#include "pathfinder.h"

#include <math.h>
#include <stdio.h>
#include <stdlib.h>


// length of one cell: 18 cm / (6 pi cm / 16*33*4 ticks) = 2016,8 ticks/cell
int length_of_cell = 2017;
// length of one cell: (18cm / 6 pi cm) * 2 pi = 6 rad
//float length_of_cell = 6;
// Wheel rotation for a 90° robot rotation
//float length_of_curve = 2.408553844;
int length_of_curve = 809;

int race_length_of_curve = 1400;

// control parameters
float k_p = 400;
float k_i = 0.5;
float k_d = 0;

float sensor_k_p = 0.003;

// error terms used by the controller. Have to be defined globally
float correction_left = 0;
float correction_right = 0;
float last_error_left = 0;
float last_error_right = 0;

float acc_error_left = 0;
float acc_error_right = 0;

int BASE_SPEED = 15;

// desired velocity in ticks per sample,
// 2112 ticks/rotation at 0.5 rotations/second
// and 100 samples/second => 10.56 ticks per sample
float v_dest_left;
float v_dest_right;

// fraction of base speed of left and right motors
float vbl = 0.04;
float vbr = 0.04;

// counter for dirty delay to avoid infinite spinning in curves.
int delay = 0;

// stores the starting position so we know how far to drive
float start_position = 0;

// used for recalibrating the encoders:
// Wall configuratin at the last measurement
int last_wall_l, last_wall_f, last_wall_r;
// true if more than half of the distance has been driven.
// Then, the sensors look into the new cell
int passed_archway;

// state variable for the motor control FSM
direction motionState = STOP;
direction raceMotionState = STOP;


/*#############################################################################
 ############################## HELPER FUNCTIONS ##############################
 ############################################################################*/

/**
 * Reset the encoders and all error terms.
 * 
 * Has to be called after every state change of the motor controller,
 * otherwise the integral part of the controller can cause problems.
 */
void resetController() {
    
        // unnecessary, maybe remove. But does not hurt to do this.
        setupMotors();
        setupSensors();
        
        // reset encoders
        setupEncoders();
        
        // set motor directions: left fwd, right fwd
        setMotorDirections_Forward();
        
        // reset error terms
        correction_left = 0;
        correction_right = 0;
        last_error_left = 0;
        last_error_right = 0;
        
        acc_error_left = 0;
        acc_error_right = 0;
        
        v_dest_left = BASE_SPEED;
        v_dest_right = BASE_SPEED;
        
        get_walls(&last_wall_l, &last_wall_f, &last_wall_r);
}


/**
 * Distance driven since the last encoder reset.
 * 
 * Returns the distance driven in the current motion, in encoder ticks.
 * Used to check for completion of a motion.
 * 
 * @return the distance driven since the last encoder reset.
 */
int distanceFromEncoderReadings() {
    return ((getPositionInCounts_1() + getPositionInCounts_2()) / 2);
}

/*#############################################################################
 ################# FUNCTIONS DEFINING THE MOTION OF THE MOUSE #################
 ############################################################################*/

/**
 * Controls both motors individually to a desired speed.
 * 
 * Implements a closed-loop PID controller.
 * Helper function for all driveForward functions.
 * 
 * @param v_l Desired speed of the left motor
 * @param v_r Desired speed of the right motor
 */
void controlFixedSpeed(float v_l, float v_r) {
    
    float left = fabs(getVelocityInCountsPerSample_1());
    float right = fabs(getVelocityInCountsPerSample_2());
    
    // P-part
    float error_l = v_l-left;
    float error_r = v_r-right;
    
    // I-part
    acc_error_left += error_l;
    acc_error_right += error_r;
    
    //D-part
    // float d_error_l = error_l - last_error_left;
    // float d_error_r = error_r - last_error_right;
    
    last_error_left = error_l;
    last_error_right = error_r;
    
    // uses the parameters from the top of this file
    correction_left = 800 + error_l * k_p + acc_error_left * k_i; // + d_error_l * k_d;
    correction_right = 800 + error_r * k_p + acc_error_right * k_i; // + d_error_r * k_d;
    
    
    if(correction_left < MOTOR_MAX) {
        if (correction_left < 0) {
            MOTORL = 0;
        } else {
            MOTORL = correction_left;
        }
    } else {
        MOTORL = MOTOR_MAX;
    }
    
    if(correction_right < MOTOR_MAX) {
        if (correction_right < 0) {
            MOTORR = 0;
        } else {
            MOTORR = correction_right;
        }
    } else {
        MOTORR = MOTOR_MAX;
    }
    
}


/**
 * Controls the mouse along a straight line.
 * 
 * Uses no sensor input, only relies on the encoders.
 */
void driveForwardBlind() {
    controlFixedSpeed(BASE_SPEED, BASE_SPEED);
}



/**
 * Controls the mouse's motion along a straight corridor. 
 * 
 * Uses the right and left sensor to stabilize the mouse in the middle of the 
 * corridor. Implements a closed-loop nested controller to do so. 
 * Uses controlFixedSpeed as the inner loop.
 */
void driveForwardAlongCorridor() {
    
    setMotorDirections_Forward();
    
    ////////////////////////////////////////////////////////////////////////
    //            outer control loop: sideways using sensors              //
    ////////////////////////////////////////////////////////////////////////
    
    int sensor_left, unused, sensor_right;
    sharpRaw(&sensor_left, &unused, &sensor_right);
    
    // v_dest ~ 10, sensor diff for 1cm ~ 800,
    // so we have to use *very* small weights
    
    v_dest_left = BASE_SPEED + (sensor_left - sensor_right) * sensor_k_p;
    v_dest_right = BASE_SPEED + (sensor_right - sensor_left) * sensor_k_p;
    
    
    ///////////////////////////////////////////////////////////////////////
    //         inner control loop, bring v_dest to the motors            //
    ///////////////////////////////////////////////////////////////////////
    
    controlFixedSpeed(v_dest_left, v_dest_right);
}
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

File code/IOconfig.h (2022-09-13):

#ifndef IOCONFIG_H
#define	IOCONFIG_H

// green LEDs
// NEVR SET LED1 AND LED3 MANUALLY! Those are connected to PWM1H1/2.
//#define LED1 LATBbits.LATB12
#define LED2 LATBbits.LATB13
//#define LED3 LATBbits.LATB14
#define LED4 LATBbits.LATB15

// LED PWM dutycycle
#define LED2DC P1DC2
#define LED4DC P1DC1

// motor PWM duty cycle
#define MOTORL P1DC1
#define MOTORR P1DC2

// motor direction
#define MOTINL1 LATBbits.LATB5
#define MOTINL2 LATBbits.LATB6
#define MOTINR1 LATBbits.LATB8
#define MOTINR2 LATBbits.LATB7

// motor enable bits when motors are inactive
#define MOTENL LATBbits.LATB14
#define MOTENR LATBbits.LATB12

#define LEDON 0
#define LEDOFF 1

#define SW1 !PORTBbits.RB5

void setupIO();

void setupLED24();
void setupLED24_PWM();
void setupMotors();
void setupSwitch();
void setupEncoders();
void setupSensors();

#endif	/* IOCONFIG_H */

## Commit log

2022-06-22 exploit phase, start of test framework
2022-06-26 complete tests, minor bugfixes
    [pathfinder.c]
2022-07-20 add sensor functions
2022-07-20 add acd / dma setup
2022-08-23 Add simplified higher-level setup functions, workaround for pin collision, and hardware tests; some cleaning up
    [IOconfig.c, IOconfig.h, dma.c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]
2022-08-23 fix possible write to CN pin
    [IOconfig.c]
2022-08-26 changed testSwitch, toggle in timer interrupt (not cn)
2022-08-31 fix motor test case
    [IOconfig.c, hw_tests.c]
2022-09-13 fix sensor pins, motors, and switch setup
    [IOconfig.c, IOconfig.h, adc.c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]
2022-09-15 some test cases for the motors, encoders, and sensors
2022-09-18 added pcb files
    [speedy_gonzalez.brd, speedy_gonzalez.sch]
2022-09-21 Add tests for PID control, nested control, and main loop
2022-10-01 more forward control, bugfixes
    [mouse_motion.c, mouse_tests.c, timer.c]
2022-10-06 3d print parts, stl, dwg, pdf
    [sg_motor_mount.dwg, sg_motor_mount.ipt, sg_motor_mount.stl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]
2022-10-14 Fix eploit phase, recalibrate on dead ends
    [motorEncoders.c, motorEncoders.h, mouse_motion.c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]
2022-10-14 make buttons work
2022-10-14 Improved calibration
2022-10-18 minor fixes, cleanup, video
    [mouse_motion.c]
